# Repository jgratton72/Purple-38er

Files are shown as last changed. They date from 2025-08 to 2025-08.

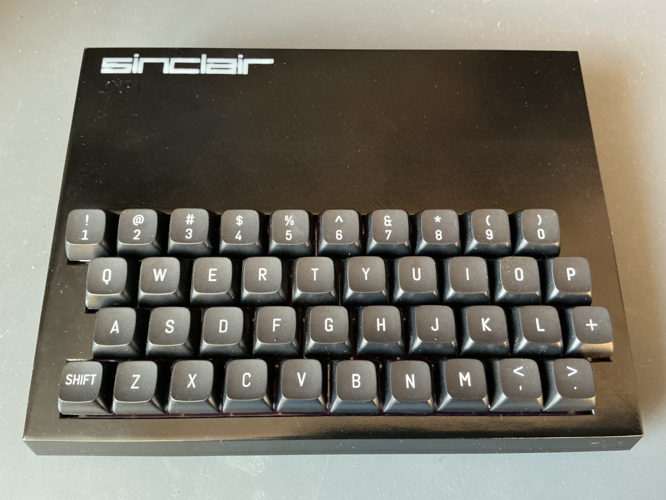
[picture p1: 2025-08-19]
Images/Assembly/IMG_1175.jpeg

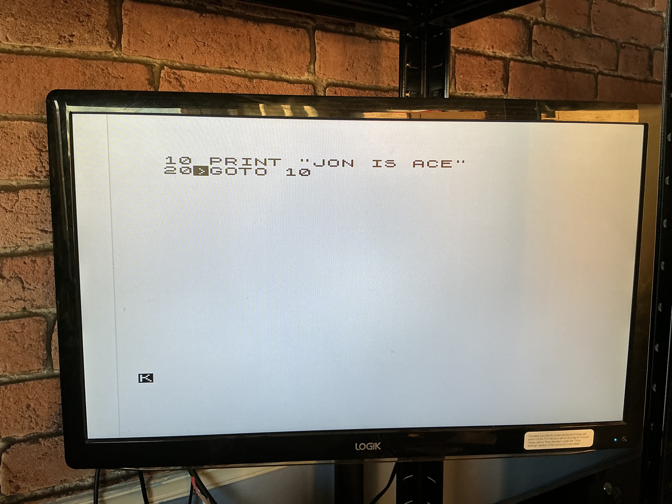
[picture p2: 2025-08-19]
Images/Assembly/IMG_1181.jpeg

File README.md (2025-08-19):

# 🟣 Purple-38er — ZX81+38 Clone (Rev 1.10)

A personal build of the **ZX81+38** clone using purple PCBs and tactile switch keys. This project documents the assembly, troubleshooting, and validation of a modern recreation of the Sinclair ZX81 using standard logic ICs and through-hole components.

---

## 🧰 Project Overview

- **Board Revision**: ZX81+38 Rev 1.10  
- **Design Origin**: Mahjongg’s open-source ZX81+38  
- **Build Variant**: Purple PCB with tactile switch keyboard  
- **Objective**: Achieve reliable boot with “K” prompt, stable composite video, and verified ROM/RAM operation

---

## 🔧 Key Components

| Component | Value / Type | Notes |
|---|---|---|
| Crystal | 13 MHz | Required for correct video timing |
| CPU | Z80A | Clocked at 3.25 MHz (÷4 from crystal)  |
| ROM | 27C256 OTP EPROM | One-time programmable; verified in chip tester |
| RAM | HM62256BLP-7 | Stable operation confirmed |
| RP2 | 22kΩ bussed network | Pull-ups for D0–D7; critical for boot  |
| 74HCU04 | Unbuffered inverter | Required for crystal oscillator |

---

## 🧪 Troubleshooting Log

- **White Screen / No “K” Prompt**:
  - All chips tested in alternate board—confirmed working  
  - RP2 replaced with 22kΩ bussed network—resolved boot issue  
  - Clock verified: 13 MHz at 74HCU04 pin 2, 3.25 MHz at Z80 pin 6

- **ROM Activity**:
  - /CS and /OE toggling observed  
  - Address and data bus activity confirmed

- **Video Output**:
  - Composite waveform present at RCA jack  
  - Sync stable after oscillator validation

---

## 📝 Build Notes

- All decoupling capacitors (100 nF) installed near ICs  
- Socketed chips reseated during debugging  
- Board now boots reliably with “K” prompt and clean composite output

---

## 📷 Visuals

The `images/` folder contains a detailed visual archive of the design and build process:

| Subfolder | Description |
|---|---|
| `Assembly/` | Final integration of keyboard and main PCB into the 3D-printed case |
| `Case 3D/` | 3D design views of the enclosure |
| `Case Printed Raw/`  | Photos of the finished, unassembled printed case |
| `Keyboard 3D/` | 3D renderings of the keyboard layout and switch matrix |
| `Keyboard Build/` | Step-by-step documentation of keyboard assembly |
| `Keycaps/` | Design files and visuals for custom keycaps |
| `PCB 3D/` | 3D views of the main PCB layout and component placement |
| `PCB Build/` | Photo documentation of the main PCB assembly process |

---

## 🛠 Assembly Notes

- **USB Power Connector**:  
   Insulate the top of the USB connector to prevent contact with the underside of the tactile switches.

- **Capacitor C9**:  
  Angle C9 flat 90 degrees away from the main board to avoid shorting against the underside of the tactile switches.
  
  ⚠️ These issues caused keyboard failure when the case was closed.

---

## 📚 References

- [ZX81+38 Original Repository](https://github.com/mahjongg2/ZX81plus38)  
- [RevSpace Project Page](https://revspace.nl/ZX81plus38_simple_to_build_ZX-81_clone)  
- [Forum64 Build Threads](https://www.forum64.de)

---

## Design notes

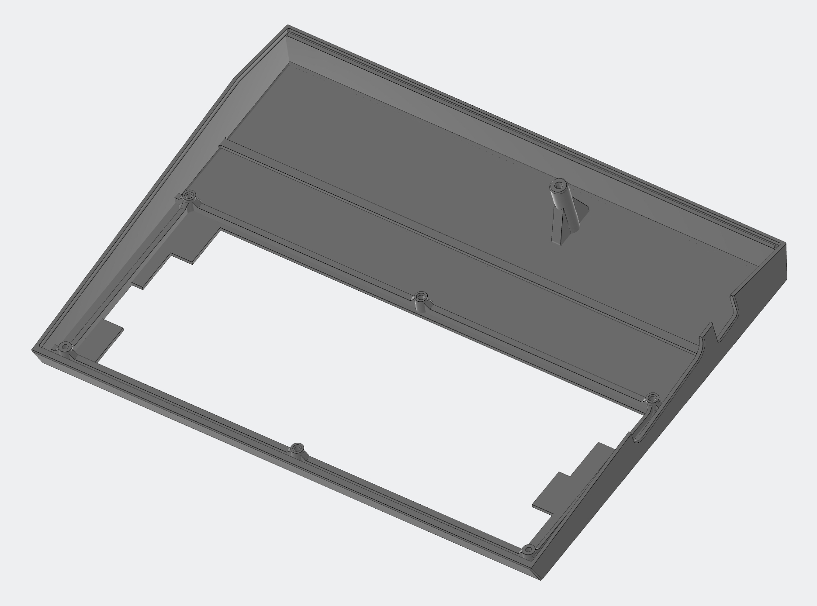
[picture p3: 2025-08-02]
Images/Case 3D/CaseTopInside3D.jpg

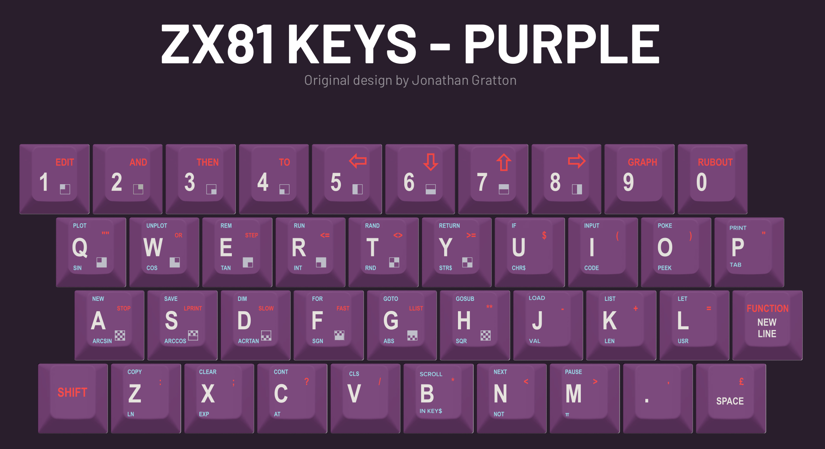
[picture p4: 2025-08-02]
Images/Keycaps/Keycaps.jpg

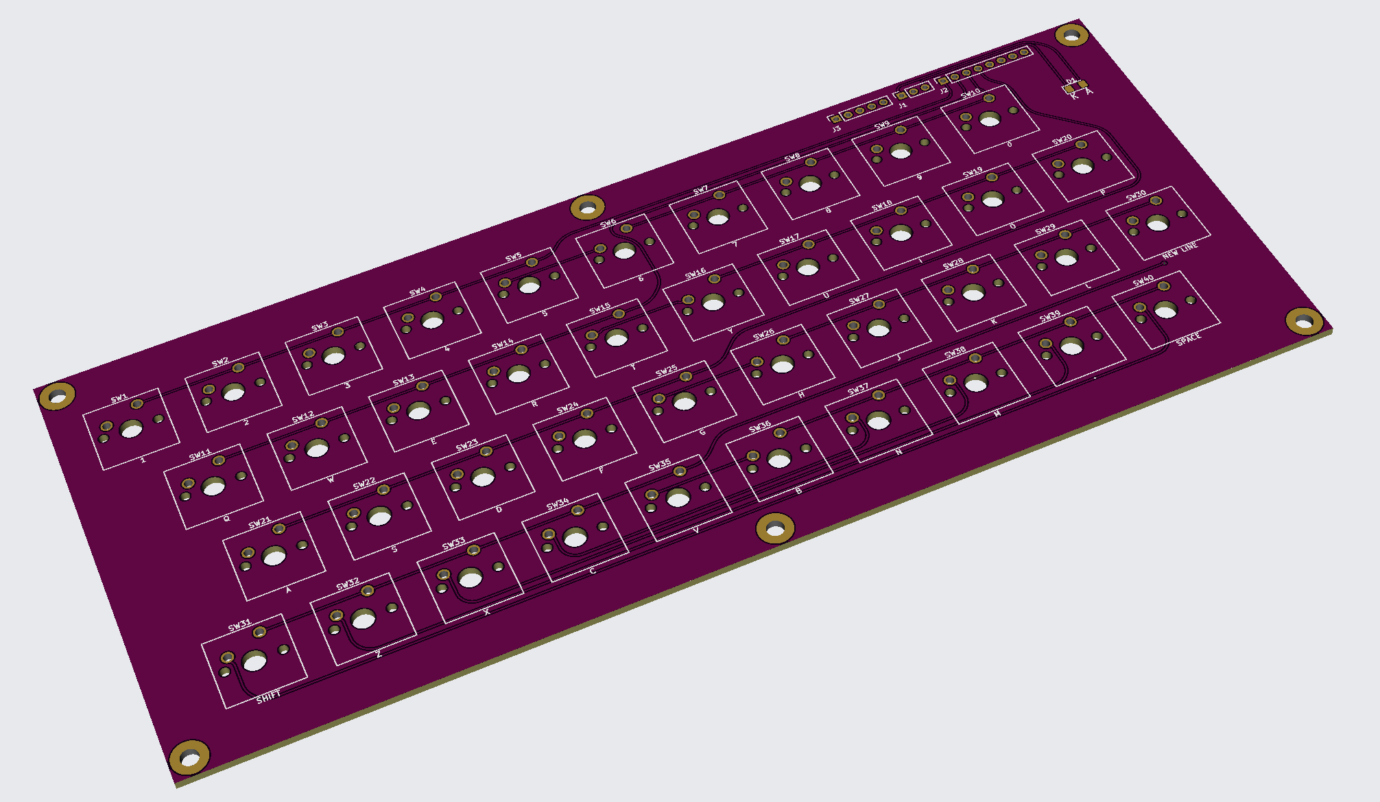
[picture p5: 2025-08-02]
Images/Keyboard 3D/Keyboard3D.jpg

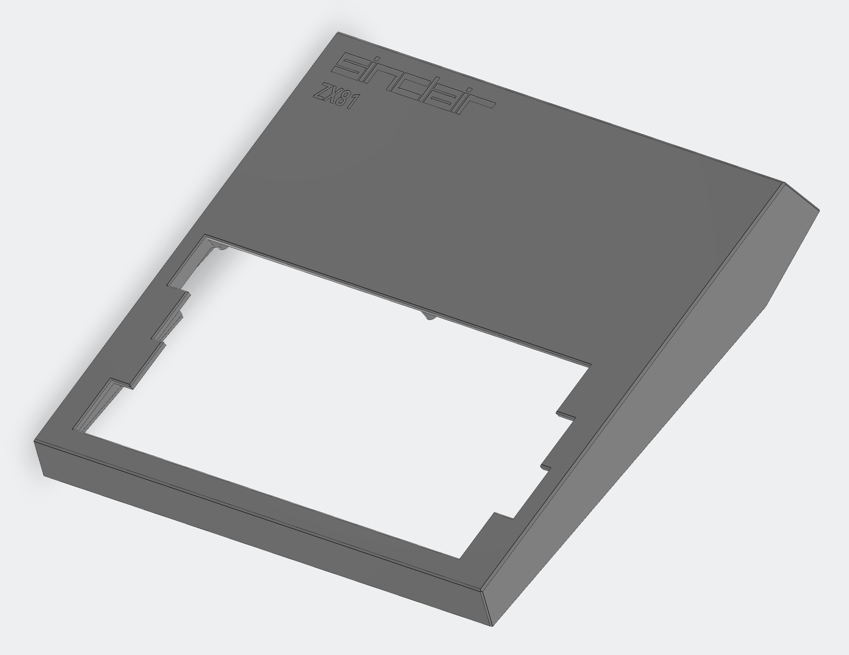
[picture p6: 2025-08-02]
Images/Case 3D/CaseTop3D.jpg

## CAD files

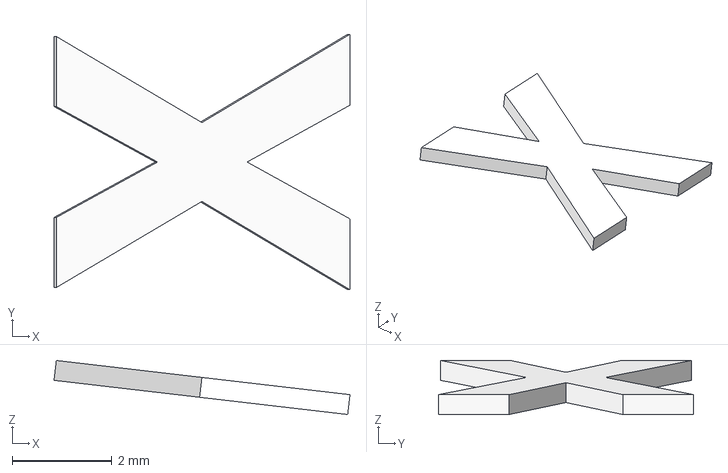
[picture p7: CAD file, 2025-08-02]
Sources/Case/Case STEP/zx81-case-zx81-2.step
5.93 x 5.12 x 1.08 mm

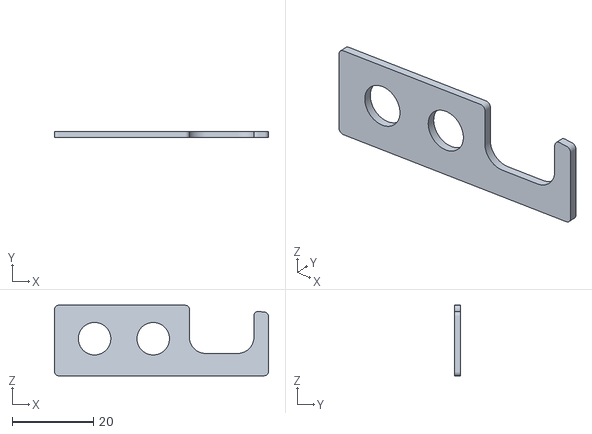
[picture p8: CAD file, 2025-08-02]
Sources/Case/Case STL/zx81-case-port-cover-usb-c.stl
52.8 x 1.60 x 17.4

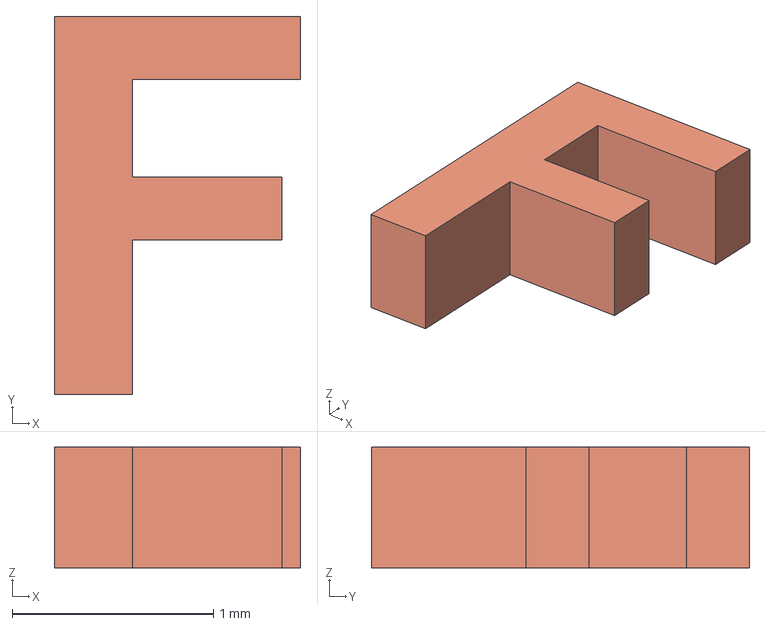
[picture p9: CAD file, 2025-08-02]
Sources/Case/Keycap STEP/zx81-keycaps-text-b-76.step
1.22 x 1.88 x 0.6 mm

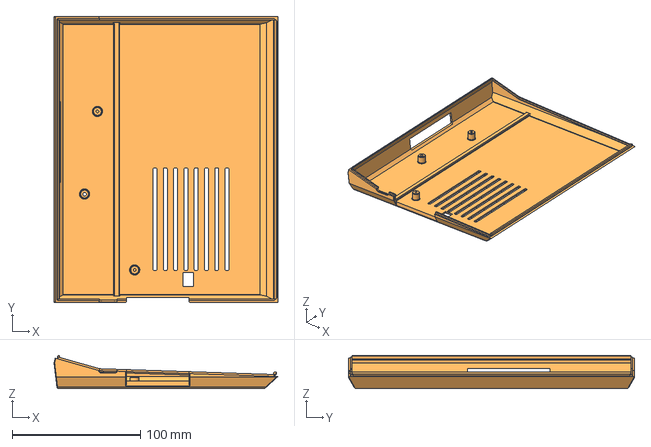
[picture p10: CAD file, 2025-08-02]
Sources/Case/Case STEP/zx81-case-bottom-zx81.step
174.4 x 223.0 x 25.7 mm

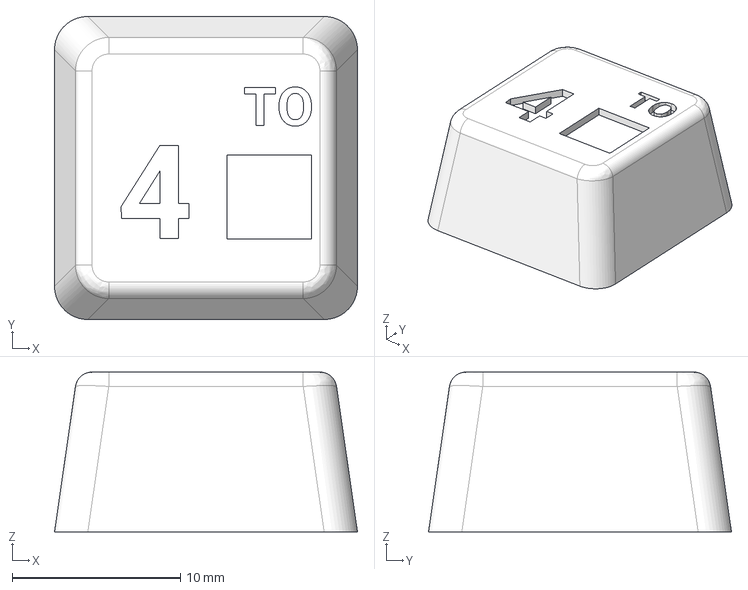
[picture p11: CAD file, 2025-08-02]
Sources/Case/Keycap STEP/zx81-keycaps-4.step
18.0 x 18.0 x 9.50 mm

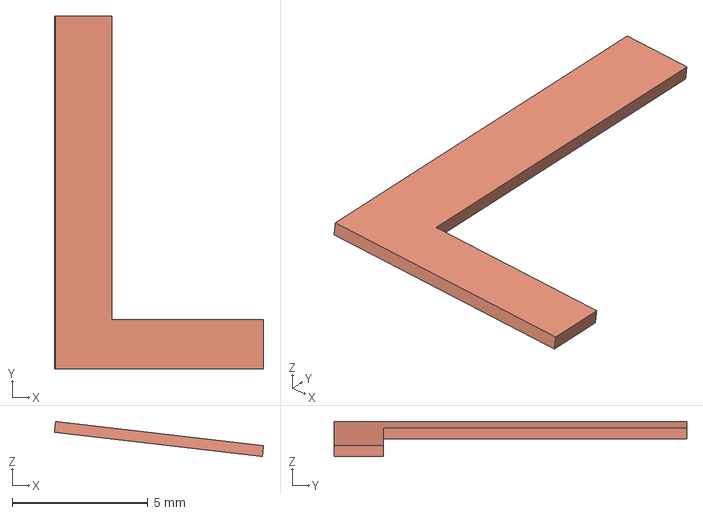
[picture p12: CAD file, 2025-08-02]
Sources/Case/Case STEP/zx81-case-sinclair.step
7.71 x 13.0 x 1.29 mm

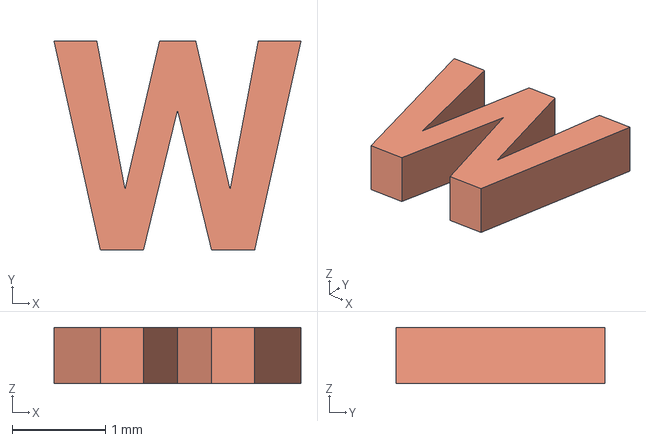
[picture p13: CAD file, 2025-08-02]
Sources/Case/Keycap STEP/zx81-keycaps-text-b-25.step
2.65 x 2.23 x 0.6 mm

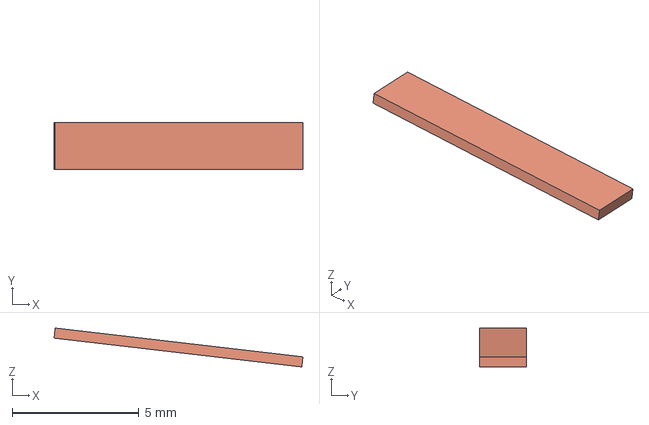
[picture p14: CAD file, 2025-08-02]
Sources/Case/Case STEP/zx81-case-sinclair-7.step
9.81 x 1.86 x 1.53 mm

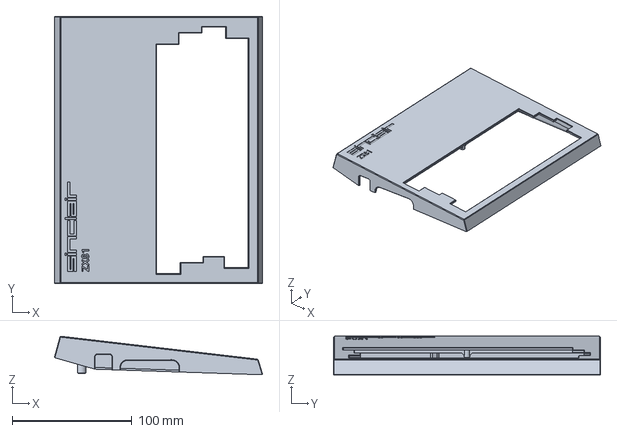
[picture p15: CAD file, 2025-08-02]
Sources/Case/Case STEP/zx81-case-top-zx81.step
174.0 x 223.0 x 32.2 mm

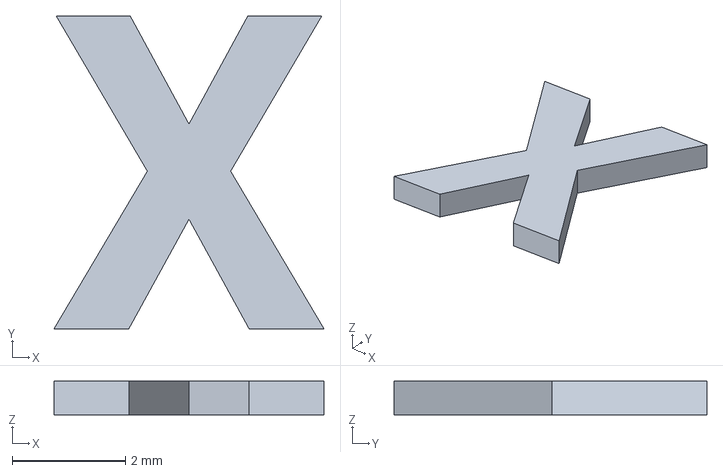
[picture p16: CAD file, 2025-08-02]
Sources/Case/Keycap STEP/zx81-keycaps-text-a-24.step
4.78 x 5.53 x 0.6 mm

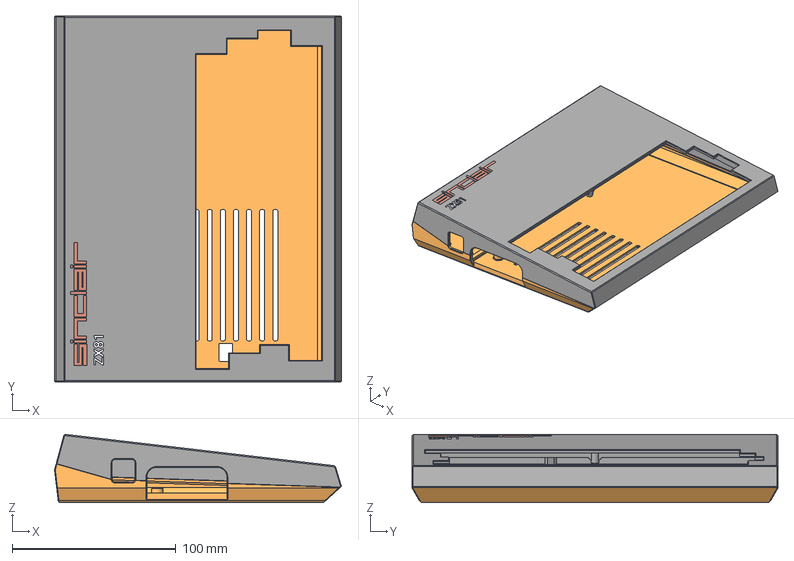
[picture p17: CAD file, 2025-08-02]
Sources/Case/Case STEP/combined-zx81-case-zx81.step
175.0 x 223.0 x 41.7 mm

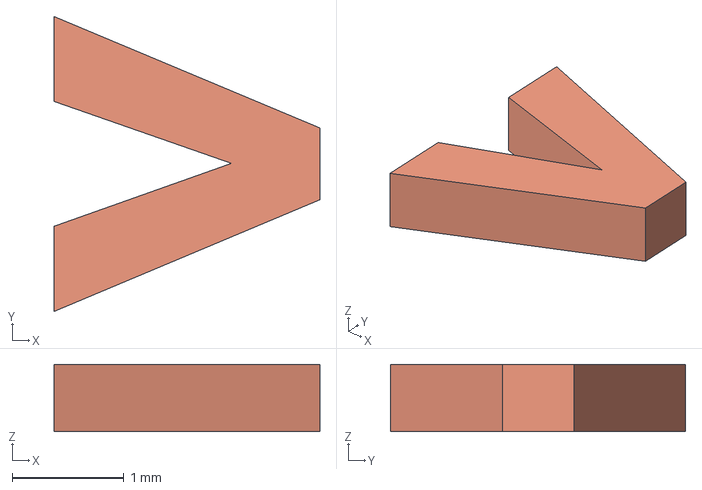
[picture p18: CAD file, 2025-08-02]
Sources/Case/Keycap STEP/zx81-keycaps-text-b-19.step
2.38 x 2.64 x 0.6 mm

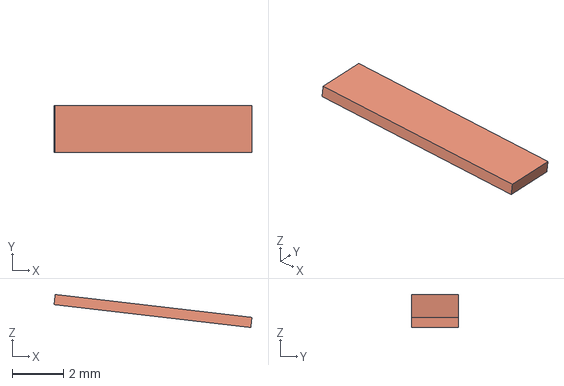
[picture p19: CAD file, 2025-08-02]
Sources/Case/Case STEP/zx81-case-sinclair-2.step
7.73 x 1.85 x 1.29 mm

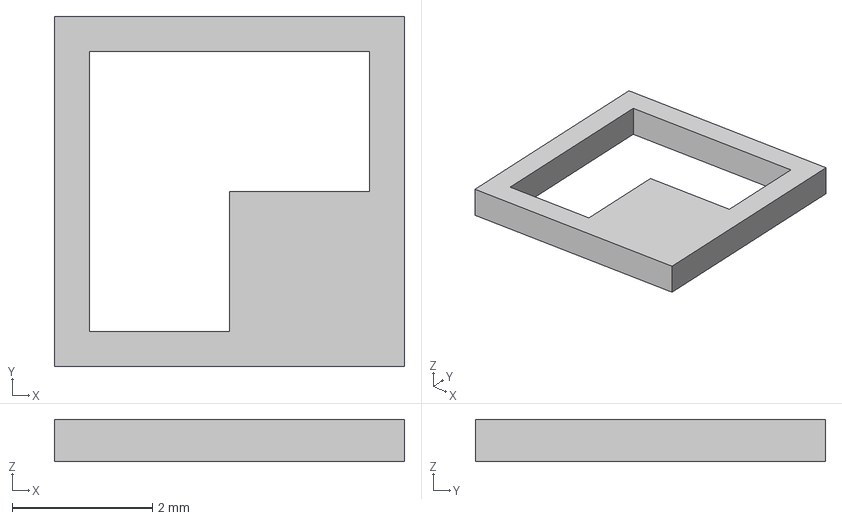
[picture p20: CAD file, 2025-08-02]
Sources/Case/Keycap STEP/zx81-keycaps-dark-19.step
5.00 x 5.00 x 0.6 mm

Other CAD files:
Sources/Case/Keycap STEP/zx81-keycaps-n.step
Sources/Case/Case STEP/zx81-case-sinclair-5.step
Sources/Case/Keycap STEP/zx81-keycaps-text-a-30.step
Sources/Case/Case STEP/zx81-case-top-timex.step
Sources/Case/Case STEP/combined-zx81-case-timex.step
Sources/Case/Case STEP/zx81-case-bottom-timex.step
Sources/Case/Case STEP/zx81-case-port-cover.step
Sources/Case/Case STEP/zx81-case-sinclair-1.step
Sources/Case/Case STEP/zx81-case-sinclair-3.step
Sources/Case/Case STEP/zx81-case-sinclair-4.step
Sources/Case/Case STEP/zx81-case-sinclair-6.step
Sources/Case/Case STEP/zx81-case-sinclair-8.step
Sources/Case/Case STEP/zx81-case-sinclair-9.step
Sources/Case/Case STEP/zx81-case-usb-mount.step
Sources/Case/Case STEP/zx81-case-zx81-1.step
Sources/Case/Case STEP/zx81-case-zx81-3.step
Sources/Case/Case STEP/zx81-case-zx81.step
Sources/Case/Case STL/zx81-case-bottom-timex.stl
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

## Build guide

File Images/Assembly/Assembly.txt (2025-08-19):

Notes.
Had to lay C9 flat and put some insulation on top of the USB power to keep them from shorting the keyboard.
before i did that the keyboard would not work when I clipped the case shut.

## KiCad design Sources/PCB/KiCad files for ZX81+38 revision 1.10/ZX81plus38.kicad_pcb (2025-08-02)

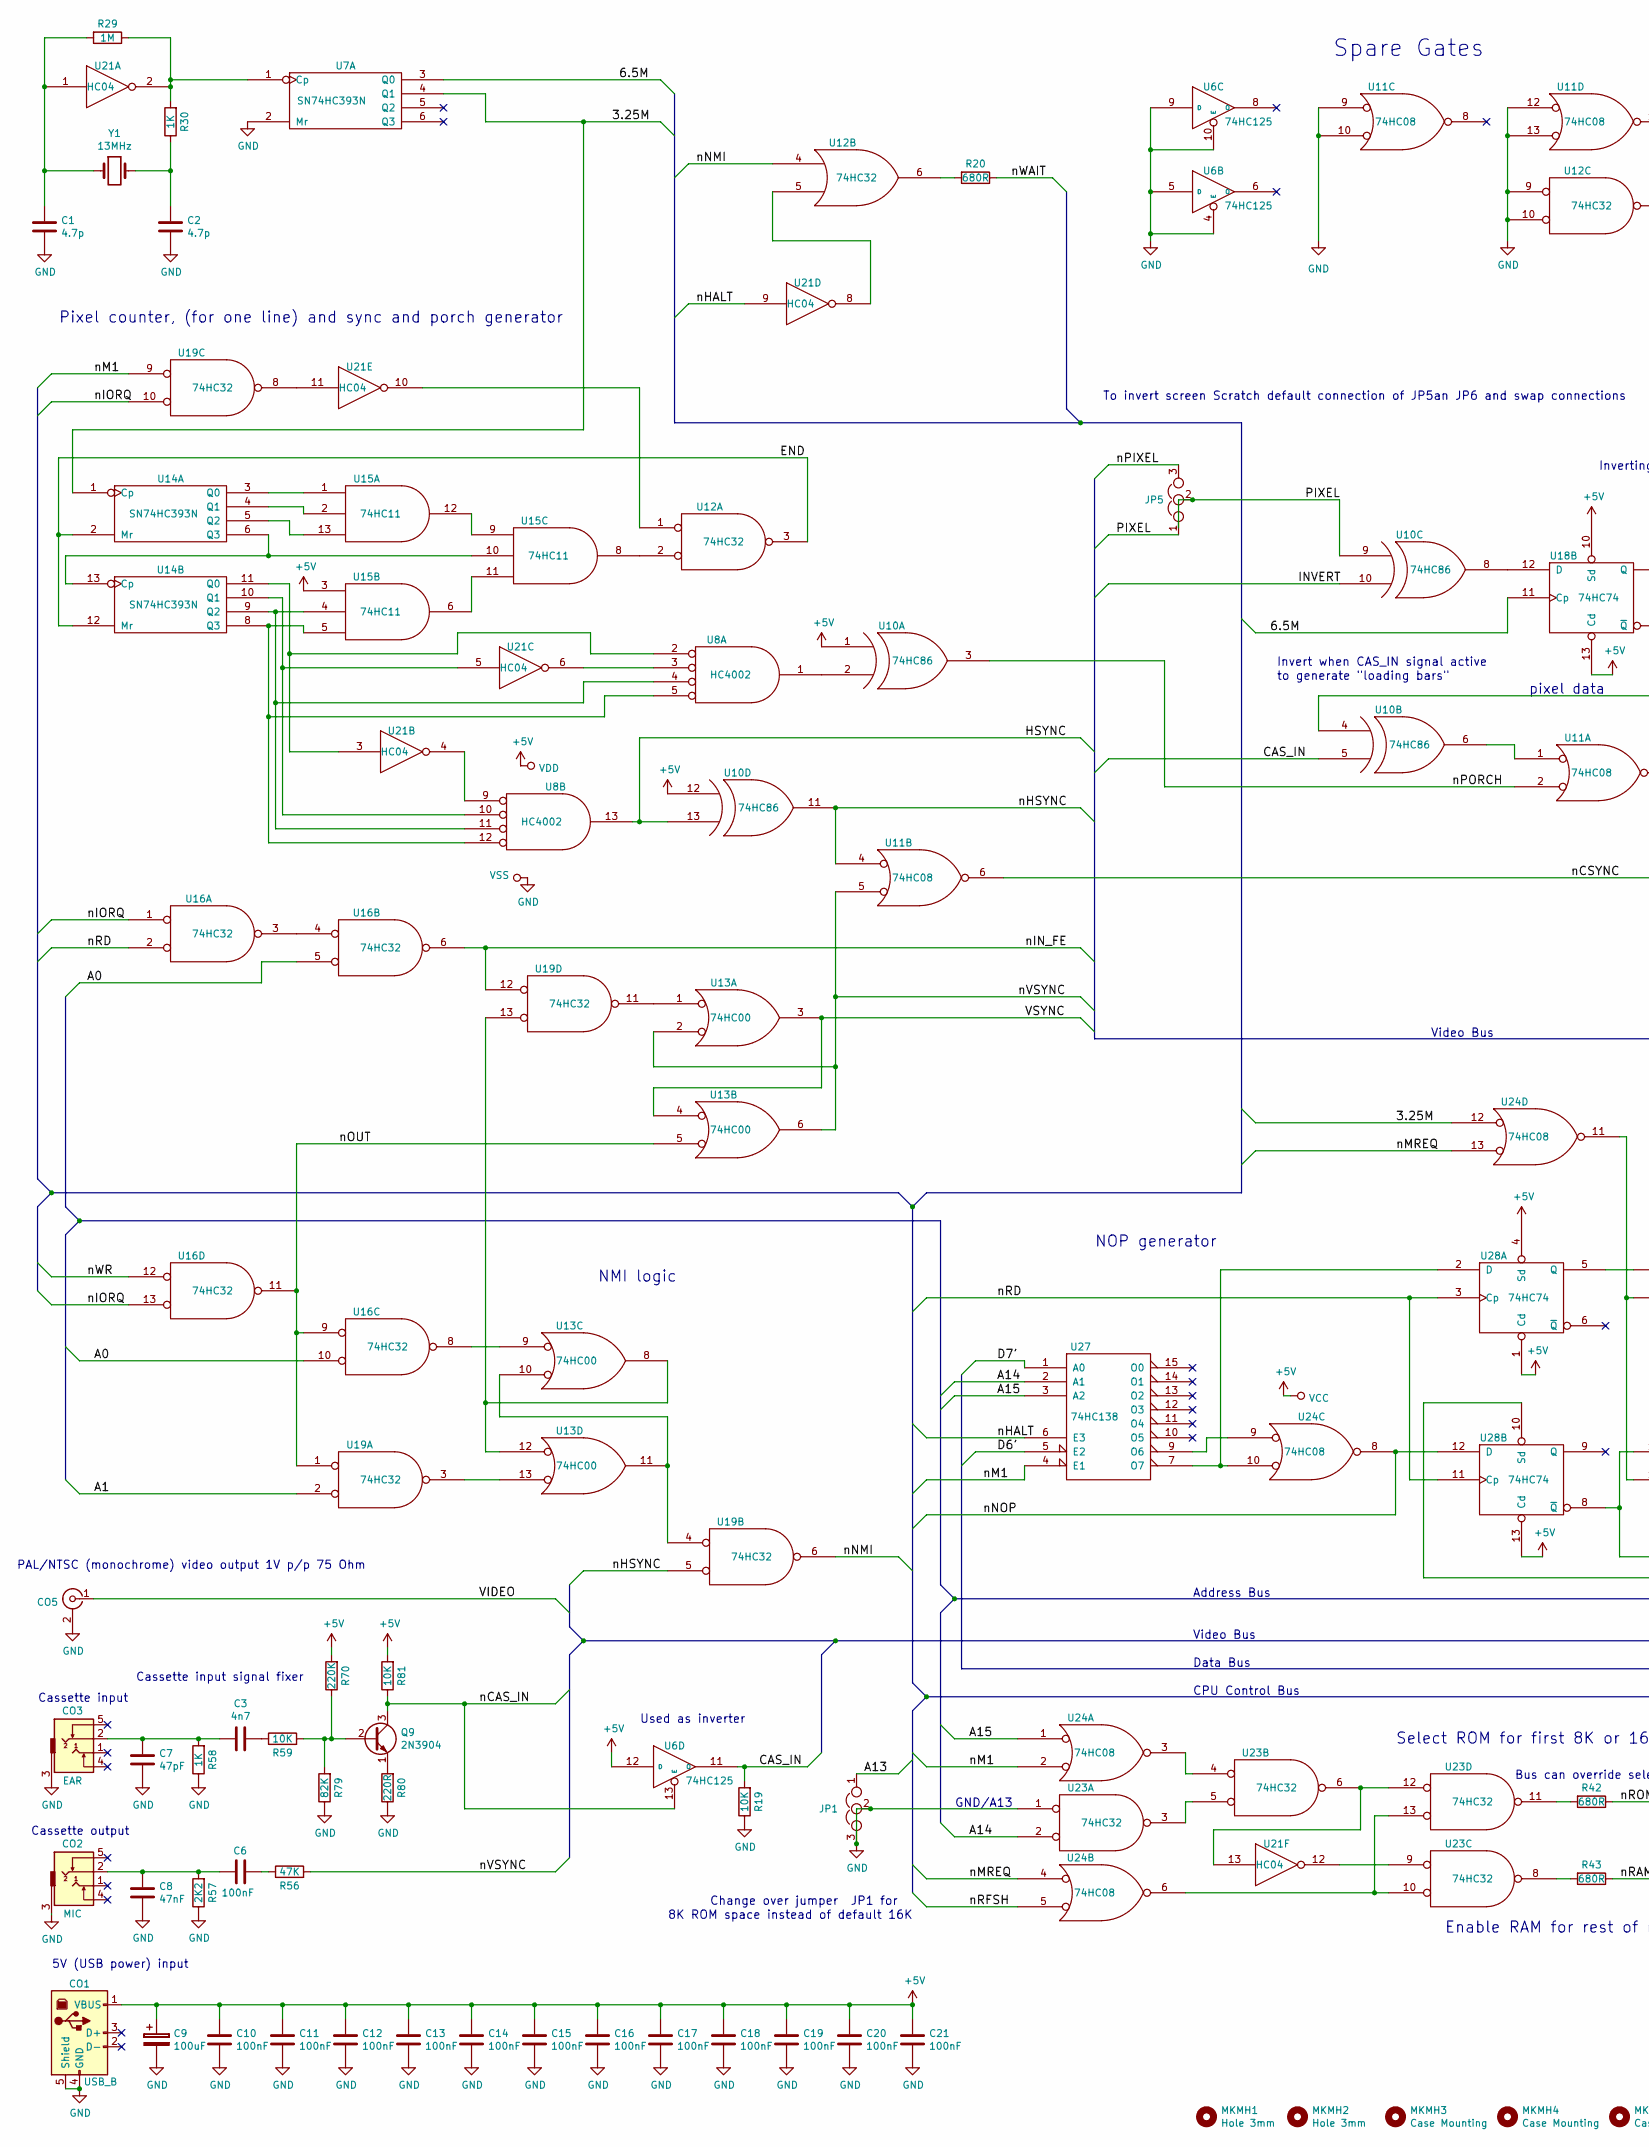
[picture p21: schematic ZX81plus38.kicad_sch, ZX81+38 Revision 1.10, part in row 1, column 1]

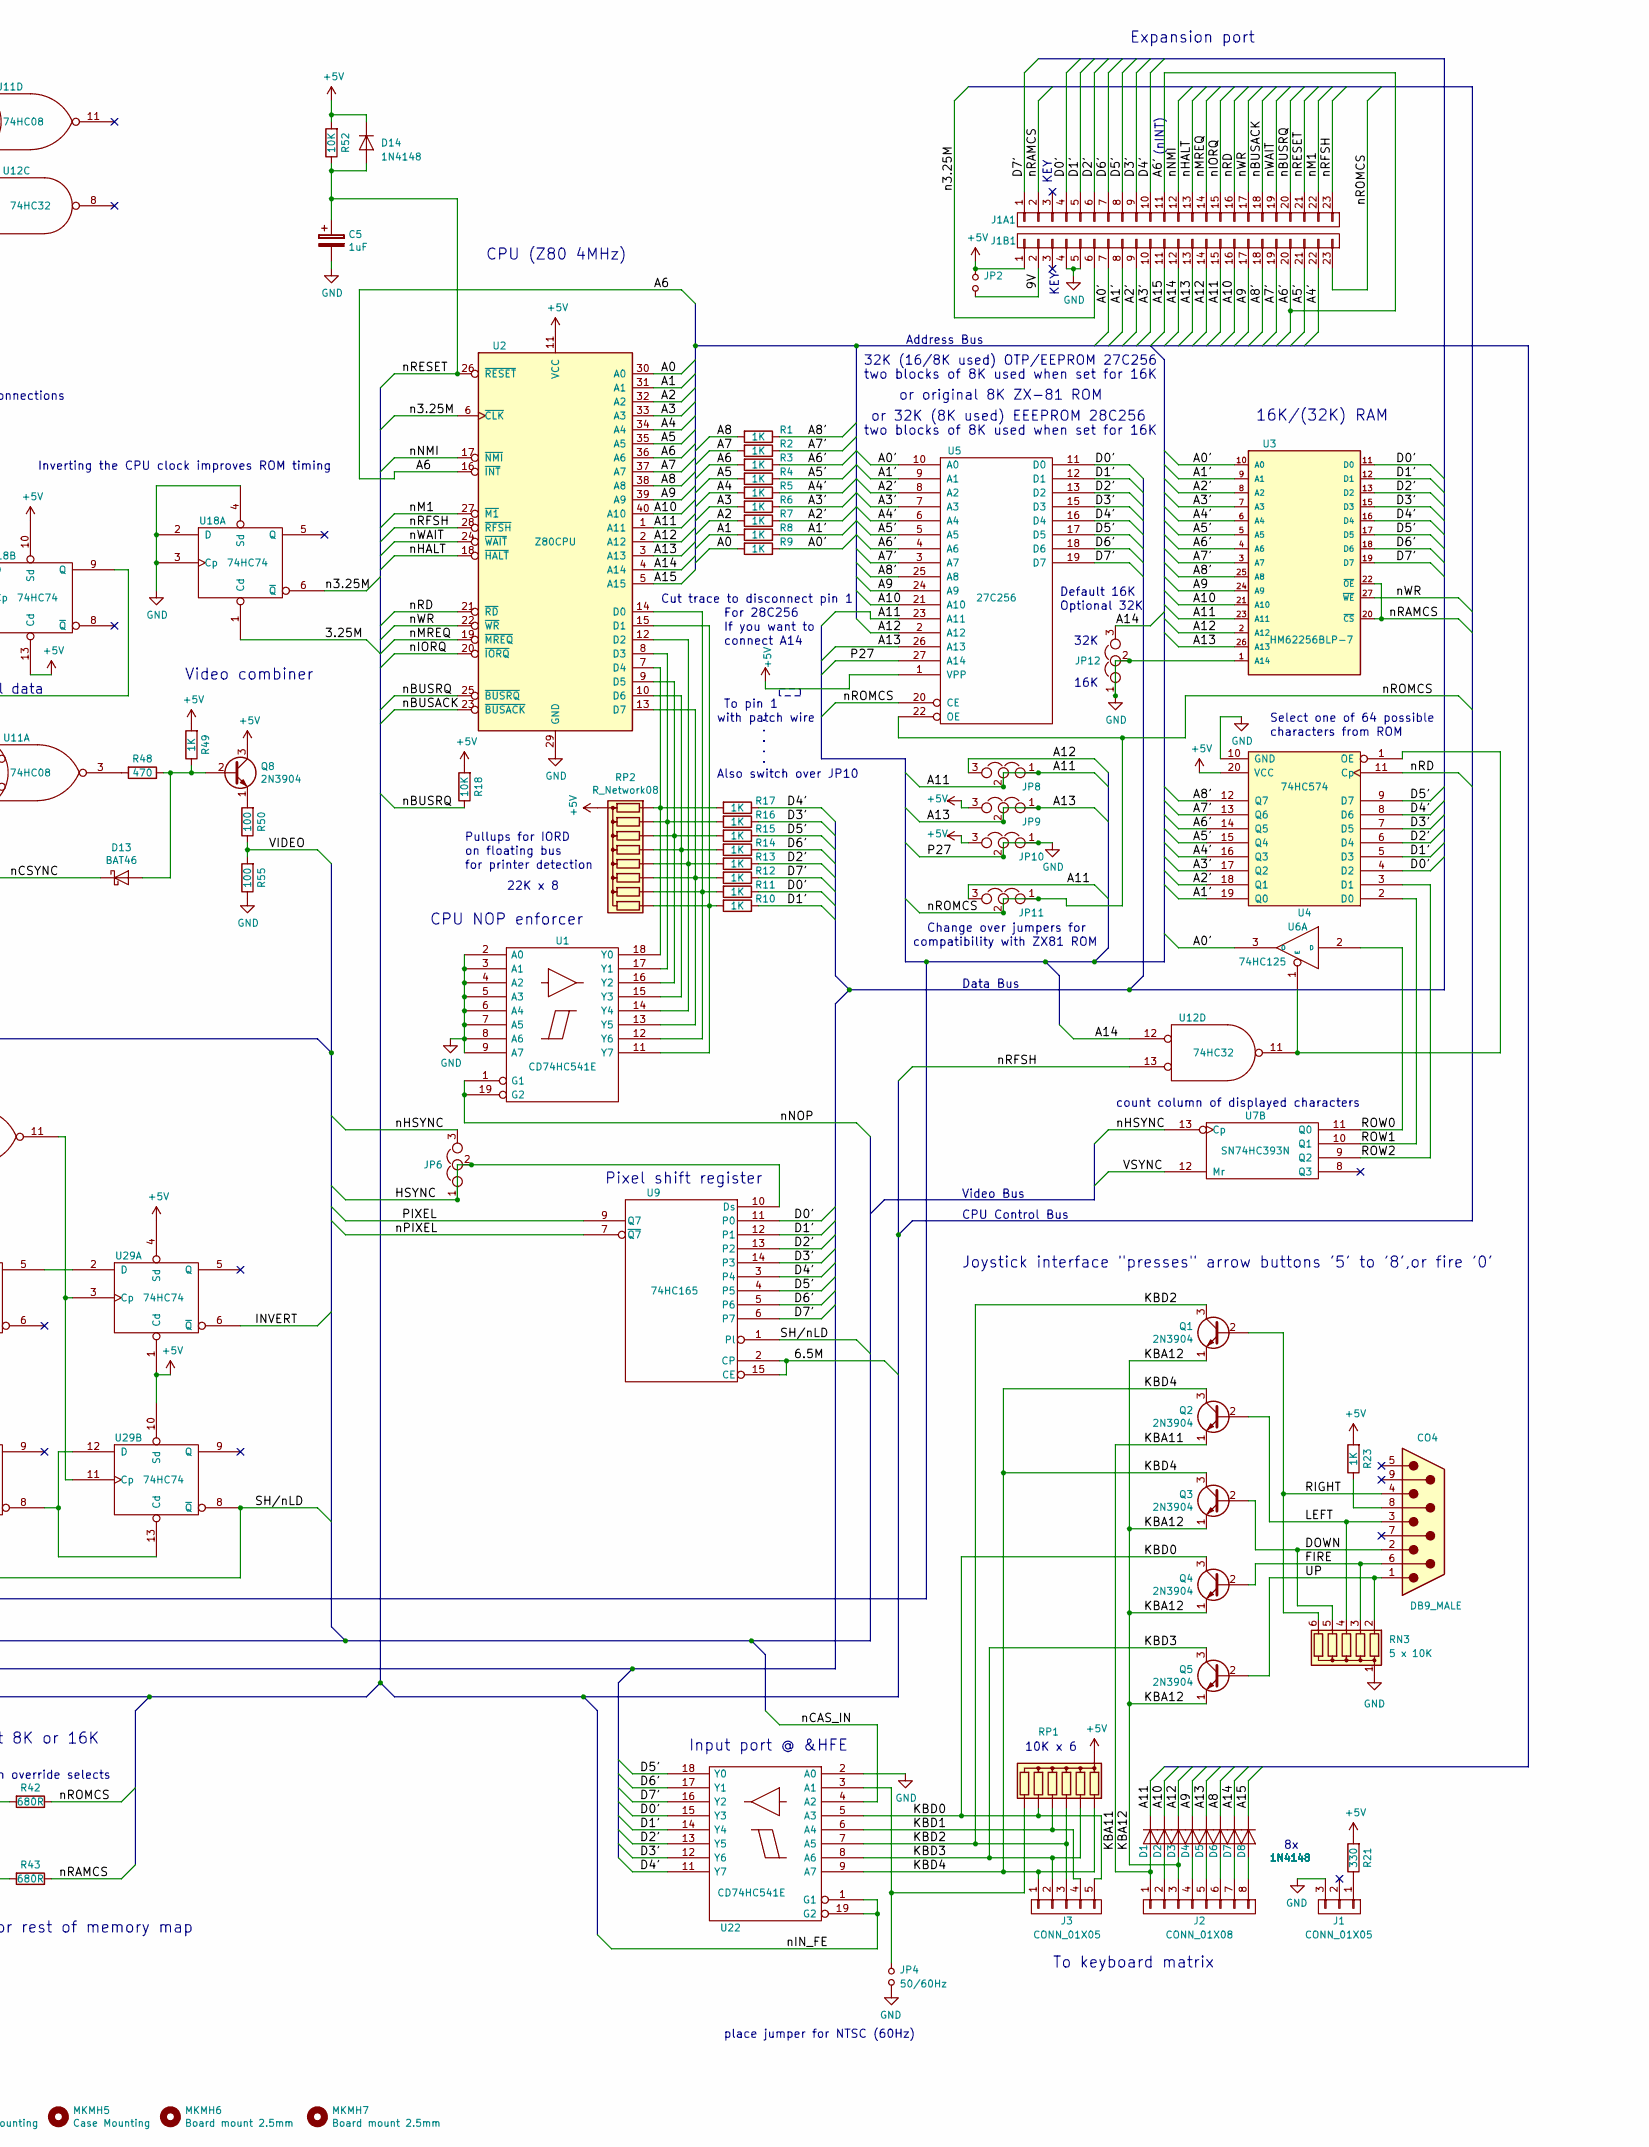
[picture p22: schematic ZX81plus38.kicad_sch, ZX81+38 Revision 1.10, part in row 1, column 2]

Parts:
C1, C2: 4.7p; C_Disc_D3.0mm_W2.0mm_P2.50mm
C3: 4n7; C_Disc_D4.7mm_W2.5mm_P5.00mm
C5: 1uF; CP_Radial_Tantal_D6.0mm_P2.50mm
C6, C10, C11, C12, C13, C14, C15, C16, C17, C18, C19, C20, C21: 100nF; C_Disc_D4.7mm_W2.5mm_P5.00mm
C7: 47pF; C_Disc_D4.7mm_W2.5mm_P5.00mm
C8: 47nF; C_Disc_D4.7mm_W2.5mm_P5.00mm
C9: 100uF; CP_Radial_Tantal_D6.0mm_P2.50mm
CO1: USB_B
CO2: MIC; SPC21348
CO3: EAR; SPC21348
CO4: DB9_MALE; dB09-MALE
CO5: CONN_COAXIAL; RCA_CONNECTOR
D1, D2, D3, D4, D5, D6, D7, D8, D14: 1N4148; D_DO-35_SOD27_P7.62mm_Horizontal
D13: BAT46; D_DO-35_SOD27_P7.62mm_Horizontal
J1: CONN_01X05; Pin_Header_Straight_1x03_Pitch2.54mm
J1A1, J1B1: CONN_01X23; Pin_Header_Straight_1x23_Pitch2.54mm
J2: CONN_01X08; Pin_Header_Straight_1x08_Pitch2.54mm
J3: CONN_01X05; Pin_Header_Straight_1x05_Pitch2.54mm
JP1, JP5, JP6, JP8, JP9, JP10, JP11, JP12: Jumper_NC_Dual; Pin_Header_Straight_1x03_Pitch2.54mm
JP2: .; Pin_Header_Straight_1x02_Pitch2.54mm
JP4: 50/60Hz; Pin_Header_Straight_1x02_Pitch2.54mm
MKMH1, MKMH2: Hole 3mm; MountingHole_3.2mm_M3
MKMH3, MKMH4, MKMH5: Case Mounting; MountingHole_3.2mm_M3
MKMH6, MKMH7: Board mount 2.5mm; MountingHole_2.5mm
Q1, Q2, Q3, Q4, Q5, Q8, Q9: 2N3904; TO-92_Molded_Narrow
R1, R2, R3, R4, R5, R6, R7, R8, R9, R10, R11, R12, R13, R14, R15, R16, R17, R23, R58: 1K; R_Axial_DIN0204_L3.6mm_D1.6mm_P2.54mm_Vertical
R18, R19, R52, R59, R81: 10K; R_Axial_DIN0204_L3.6mm_D1.6mm_P2.54mm_Vertical
R20, R42, R43: 680R; R_Axial_DIN0204_L3.6mm_D1.6mm_P2.54mm_Vertical
R21: 330; R_Axial_DIN0207_L6.3mm_D2.5mm_P7.62mm_Horizontal
R29: 1M; R_Axial_DIN0207_L6.3mm_D2.5mm_P7.62mm_Horizontal
R30, R49: 1K; R_Axial_DIN0207_L6.3mm_D2.5mm_P7.62mm_Horizontal
R48: 470; R_Axial_DIN0207_L6.3mm_D2.5mm_P7.62mm_Horizontal
R50, R55: 100; R_Axial_DIN0207_L6.3mm_D2.5mm_P7.62mm_Horizontal
R56: 47K; R_Axial_DIN0204_L3.6mm_D1.6mm_P2.54mm_Vertical
R57: 2K2; R_Axial_DIN0204_L3.6mm_D1.6mm_P2.54mm_Vertical
R70: 220K; R_Axial_DIN0204_L3.6mm_D1.6mm_P2.54mm_Vertical
R79: 82K; R_Axial_DIN0204_L3.6mm_D1.6mm_P2.54mm_Vertical
R80: 220R; R_Axial_DIN0204_L3.6mm_D1.6mm_P2.54mm_Vertical
RN3: 5 x 10K; R_Array_SIP6
RP1: R_Network06; R_Array_SIP7
RP2: R_Network08; R_Array_SIP9
U1, U22: CD74HC541E; DIP-20_Ideal
U2: Z80CPU; DIP-40_ideal
U3: HM62256BLP-7; DIP-28_Ideal
U4: 74HC574; DIP-20_Ideal
U5: 27C256; DIP-28_Ideal
U6: 74HC125; DIP-14_Socket_Ideal
U7, U14: SN74HC393N; DIP-14_Socket_Ideal
U8: HC4002; DIP-14_Socket_Ideal
U9: 74HC165; DIP-16_Ideal
U10: 74HC86; DIP-14_Socket_Ideal
U11, U24: 74HC08; DIP-14_Socket_Ideal
U12, U16, U19, U23: 74HC32; DIP-14_Socket_Ideal
U13: 74HC00; DIP-14_Socket_Ideal
U15: 74HC11; DIP-14_Socket_Ideal
U18, U28, U29: 74HC74; DIP-14_Socket_Ideal
U21: HC04; DIP-14_Socket_Ideal
U27: 74HC138; DIP-16_Ideal
Y1: 13MHz; Crystal_SMD_HC49-SD

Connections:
+5V: C9.1, C10.2, C11.2, C12.2, C13.2, C14.2, C15.2, C16.2, C17.2, C18.2, C19.2, C20.2, C21.2, CO1.1 (VBUS), D14.1 (K), J1B1.1, JP2.1, JP9.3, JP10.3, Q8.3 (C), R18.2, R21.2, R23.2, R49.2, R52.2, R70.2, R81.2, RP1.1 (common), RP2.1 (common), U1.20 (VCC), U2.11 (VCC), U3.28 (VCC), U4.20 (VCC), U5.1 (VPP), U5.28 (VCC), U6.12 (D), U6.14 (VCC), U7.14 (VCC), U8.14 (VDD), U9.16 (VCC), U10.1 (IN1), U10.12 (IN1), U10.14 (VCC), U11.14 (VCC), U12.14 (VCC), U13.14 (VCC), U14.14 (VCC), U15.3, U15.14 (VCC), U16.14 (VCC), U18.10 (Sd), U18.13 (Cd), U18.14 (VCC), U19.14 (VCC), U21.14 (VCC), U22.20 (VCC), U23.14 (VCC), U24.14 (VCC), U27.16 (VCC), U28.1 (Cd), U28.4 (Sd), U28.13 (Cd), U28.14 (VCC), U29.1 (Cd), U29.4 (Sd), U29.10 (Sd), U29.14 (VCC)
/3.25M: U7.4 (Q1), U14.1 (Cp), U18.1 (Cd), U24.12
/6.5M: U7.3 (Q0), U9.2 (CP), U9.15 (CE), U18.11 (Cp)
/9V: J1B1.2, JP2.2
/A0: R9.2, U2.30 (A0), U16.5, U16.10
/A0': J1B1.7, R9.1, U3.10 (A0), U5.10 (A0), U6.3 (O)
/A1: R8.2, U2.31 (A1), U19.2
/A1': J1B1.8, R8.1, U3.9 (A1), U4.19 (Q0), U5.9 (A1)
/A2: R7.2, U2.32 (A2)
/A2': J1B1.9, R7.1, U3.8 (A2), U4.18 (Q1), U5.8 (A2)
/A3: R6.2, U2.33 (A3)
/A3': J1B1.10, R6.1, U3.7 (A3), U4.17 (Q2), U5.7 (A3)
/A4: R5.2, U2.34 (A4)
/A4': J1B1.22, R5.1, U3.6 (A4), U4.16 (Q3), U5.6 (A4)
/A5: R4.2, U2.35 (A5)
/A5': J1B1.21, R4.1, U3.5 (A5), U4.15 (Q4), U5.5 (A5)
/A6: R3.2, U2.16 (~INT), U2.36 (A6)
/A6': J1A1.11, J1B1.20, R3.1, U3.4 (A6), U4.14 (Q5), U5.4 (A6)
/A7: R2.2, U2.37 (A7)
/A7': J1B1.19, R2.1, U3.3 (A7), U4.13 (Q6), U5.3 (A7)
/A8: D6.1 (K), R1.2, U2.38 (A8)
/A8': J1B1.18, R1.1, U3.25 (A8), U4.12 (Q7), U5.25 (A8)
/A9: D4.1 (K), J1B1.17, U2.39 (A9), U3.24 (A9), U5.24 (A9)
/A10: D2.1 (K), J1B1.16, U2.40 (A10), U3.21 (A10), U5.21 (A10)
/A11: D1.1 (K), J1B1.15, JP8.1, JP8.2, JP11.3, U2.1 (A11), U3.23 (A11), U5.23 (A11)
/A12: D3.1 (K), J1B1.14, JP8.3, U2.2 (A12), U3.2 (A12), U5.2 (A12)
/A13: D5.1 (K), J1B1.13, JP1.1, JP9.1, JP9.2, U2.3 (A13), U3.26 (A13), U5.26 (A13)
/A14: D7.1 (K), J1B1.12, JP12.3, U2.4 (A14), U12.12, U23.2, U27.2 (A1)
/A15: D8.1 (K), J1B1.11, U2.5 (A15), U24.1, U27.3 (A2)
/CAS_IN: R19.2, U6.11 (O), U10.5 (IN2)
/D0': J1A1.4, R11.1, U3.11 (D0), U4.4 (D2), U5.11 (D0), U9.11 (P0), U22.15 (Y3)
/D1': J1A1.5, R10.1, U3.12 (D1), U4.5 (D3), U5.12 (D1), U9.12 (P1), U22.14 (Y4)
/D2': J1A1.6, R13.1, U3.13 (D2), U4.6 (D4), U5.13 (D2), U9.13 (P2), U22.13 (Y5)
/D3': J1A1.9, R16.1, U3.15 (D3), U4.7 (D5), U5.15 (D3), U9.14 (P3), U22.12 (Y6)
/D4': J1A1.10, R17.1, U3.16 (D4), U4.8 (D6), U5.16 (D4), U9.3 (P4), U22.11 (Y7)
/D5': J1A1.8, R15.1, U3.17 (D5), U4.9 (D7), U5.17 (D5), U9.4 (P5), U22.18 (Y0)
/D6': J1A1.7, R14.1, U3.18 (D6), U5.18 (D6), U9.5 (P6), U22.17 (Y1), U27.5 (E2)
/D7': J1A1.1, R12.1, U3.19 (D7), U5.19 (D7), U9.6 (P7), U22.16 (Y2), U27.1 (A0)
/DOWN: CO4.2, Q3.2 (B), RN3.5 (R4)
/END: U12.3, U14.2 (Mr), U14.12 (Mr)
/FIRE: CO4.6, Q4.2 (B), RN3.3 (R2)
/HSYNC: JP6.1, JP6.2, U8.13, U9.10 (Ds), U10.13 (IN2)
/INVERT: U10.10 (IN2), U29.6 (~Q)
/KBA11: D1.2 (A), J2.1, Q2.1 (E)
/KBA12: D3.2 (A), J2.3, Q1.1 (E), Q3.1 (E), Q4.1 (E), Q5.1 (E)
/KBD0: J3.5, Q4.3 (C), RP1.6 (R5), U22.5 (A3)
/KBD1: J3.4, RP1.5 (R4), U22.6 (A4)
/KBD2: J3.3, Q1.3 (C), RP1.4 (R3), U22.7 (A5)
/KBD3: J3.2, Q5.3 (C), RP1.3 (R2), U22.8 (A6)
/KBD4: J3.1, Q2.3 (C), Q3.3 (C), RP1.2 (R1), U22.9 (A7)
/LEFT: CO4.3, Q2.2 (B), RN3.4 (R3)
/PIXEL: JP5.1, JP5.2, U9.9 (Q7), U10.9 (IN1)
/RIGHT: CO4.4, Q1.2 (B), RN3.6 (R5)
/ROW0: U6.2 (D), U7.11 (Q0)
/ROW1: U4.2 (D0), U7.10 (Q1)
/ROW2: U4.3 (D1), U7.9 (Q2)
/SH/nLD: U9.1 (Pl), U28.10 (Sd), U29.8 (~Q)
/UP: CO4.1, Q5.2 (B), RN3.2 (R1)
/VIDEO: CO5.1 (In), R50.1, R55.2
/VSYNC: U7.12 (Mr), U13.3, U13.4
/n3.25M: J1B1.6, U2.6 (~CLK), U18.6 (~Q)
/nBUSACK: J1A1.18, U2.23 (~BUSACK)
/nBUSRQ: J1A1.20, R18.1, U2.25 (~BUSRQ)
/nCAS_IN: Q9.3 (C), R81.1, U6.13 (E), U22.4 (A2)
/nCSYNC: D13.1 (K), U11.6
/nHALT: J1A1.13, U2.18 (~HALT), U21.9, U27.6 (E3)
/nHSYNC: JP6.3, U7.13 (Cp), U10.11 (OUT), U11.4, U19.5
/nIN_FE: U16.6, U19.12, U22.1 (G1), U22.19 (G2)
/nIORQ: J1A1.15, U2.20 (~IORQ), U16.1, U16.13, U19.10
/nM1: J1A1.22, U2.27 (~M1), U19.9, U24.2, U27.4 (E1)
/nMREQ: J1A1.14, U2.19 (~MREQ), U24.4, U24.13
/nNMI: J1A1.12, U2.17 (~NMI), U12.4, U19.6
/nNOP: U1.1 (G1), U1.19 (G2), U24.8, U28.12 (D)
/nOUT: U13.5, U16.9, U16.11, U19.1
/nPIXEL: JP5.3, U9.7 (~Q7)
/nPORCH: U10.3 (OUT), U11.2
/nRAMCS: J1A1.2, R43.1, U3.20 (~CS), U3.22 (~OE)
/nRD: J1A1.16, U2.21 (~RD), U4.11 (Cp), U16.2, U28.3 (Cp), U28.11 (Cp)
/nRESET: C5.1, D14.2 (A), J1A1.21, R52.1, U2.26 (~RESET)
/nRFSH: J1A1.23, U2.28 (~RFSH), U12.13, U24.5
/nROMCS: J1B1.23, JP11.1, JP11.2, R42.1, U5.20 (CE), U5.22 (OE)
/nVSYNC: R56.2, U11.5, U13.2, U13.6
/nWAIT: J1A1.19, R20.1, U2.24 (~WAIT)
/nWR: J1A1.17, U2.22 (~WR), U3.27 (~WE), U16.12
GND: C1.2, C2.2, C5.2, C7.2, C8.2, C9.2, C10.1, C11.1, C12.1, C13.1, C14.1, C15.1, C16.1, C17.1, C18.1, C19.1, C20.1, C21.1, CO1.4 (GND), CO1.5 (Shield), CO2.3, CO3.3, CO5.2 (Ext), J1.3, J1B1.4, J1B1.5, JP1.2, JP1.3, JP4.2, JP10.1, JP10.2, JP12.1, JP12.2, R19.1, R55.1, R57.1, R58.1, R79.1, R80.1, RN3.1 (common), U1.2 (A0), U1.3 (A1), U1.4 (A2), U1.5 (A3), U1.6 (A4), U1.7 (A5), U1.8 (A6), U1.9 (A7), U1.10 (GND), U2.29 (GND), U3.1 (A14), U3.14 (GND), U4.10 (GND), U5.14 (GND), U5.27 (A14), U6.4 (E), U6.5 (D), U6.7 (GND), U6.9 (D), U6.10 (E), U7.2 (Mr), U7.7 (GND), U8.7 (VSS), U9.8 (GND), U10.7 (GND), U11.7 (GND), U11.9, U11.10, U11.12, U11.13, U12.7 (GND), U12.9, U12.10, U13.7 (GND), U14.7 (GND), U15.7 (GND), U16.7 (GND), U18.2 (D), U18.3 (Cp), U18.4 (Sd), U18.7 (GND), U19.7 (GND), U21.7 (GND), U22.2 (A0), U22.10 (GND), U23.1, U23.7 (GND), U24.7 (GND), U27.8 (GND), U28.7 (GND), U29.7 (GND)
unnamed: C1.1, R29.2, U21.1, Y1.1
unnamed: C2.1, R30.1, Y1.2
unnamed: C3.1, R59.1
unnamed: C3.2, C7.1, CO3.2, R58.2
unnamed: C6.1, R56.1
unnamed: C6.2, C8.1, CO2.2, R57.2
unnamed: CO4.8, R23.1
unnamed: D2.2 (A), J2.2
unnamed: D4.2 (A), J2.4
unnamed: D5.2 (A), J2.5
unnamed: D6.2 (A), J2.6
unnamed: D7.2 (A), J2.7
unnamed: D8.2 (A), J2.8
unnamed: D13.2 (A), Q8.2 (B), R48.1, R49.1
unnamed: J1.1, R21.1
unnamed: JP4.1, RP1.7 (R6), U22.3 (A1)
unnamed: Q8.1 (E), R50.2
unnamed: Q9.1 (E), R80.2
unnamed: Q9.2 (B), R59.2, R70.1, R79.2
unnamed: R10.2, RP2.9 (R8), U1.11 (Y7), U2.15 (D1)
unnamed: R11.2, RP2.8 (R7), U1.12 (Y6), U2.14 (D0)
unnamed: R12.2, RP2.7 (R6), U1.13 (Y5), U2.13 (D7)
unnamed: R13.2, RP2.6 (R5), U1.14 (Y4), U2.12 (D2)
unnamed: R14.2, RP2.5 (R4), U1.15 (Y3), U2.10 (D6)
unnamed: R15.2, RP2.4 (R3), U1.16 (Y2), U2.9 (D5)
unnamed: R16.2, RP2.3 (R2), U1.17 (Y1), U2.8 (D3)
unnamed: R17.2, RP2.2 (R1), U1.18 (Y0), U2.7 (D4)
unnamed: R20.2, U12.6
unnamed: R29.1, R30.2, U7.1 (Cp), U21.2
unnamed: R42.2, U23.11
unnamed: R43.2, U23.8
unnamed: R48.2, U11.3
unnamed: U8.1, U10.2 (IN2)
unnamed: U10.4 (IN1), U18.9 (Q)
unnamed: U10.6 (OUT), U11.1
unnamed: U10.8 (OUT), U18.12 (D)
unnamed: U12.1, U21.10
unnamed: U12.2, U15.8
unnamed: U12.5, U21.8
unnamed: U4.1 (OE), U6.1 (E), U12.11
unnamed: U13.1, U19.11
unnamed: U13.9, U16.8
unnamed: U13.10, U13.11, U19.4
unnamed: U13.8, U13.12, U19.13
unnamed: U13.13, U19.3
unnamed: U14.3 (Q0), U15.1
unnamed: U14.4 (Q1), U15.2
unnamed: U14.5 (Q2), U15.13
unnamed: U8.5, U8.12, U14.8 (Q3), U15.5
unnamed: U8.4, U8.11, U14.9 (Q2), U15.4
unnamed: U8.10, U14.10 (Q1), U21.5
unnamed: U8.2, U14.11 (Q0), U21.3
unnamed: U14.6 (Q3), U14.13 (Cp), U15.10
unnamed: U15.6, U15.11
unnamed: U15.9, U15.12
unnamed: U16.3, U16.4
unnamed: U19.8, U21.11
unnamed: U8.9, U21.4
unnamed: U8.3, U21.6
unnamed: U21.12, U23.9
unnamed: U21.13, U23.6, U23.12
unnamed: U23.3, U23.5
unnamed: U23.4, U24.3
unnamed: U23.10, U23.13, U24.6
unnamed: U24.9, U27.9 (O6)
unnamed: U24.10, U27.7 (O7), U28.2 (D)
unnamed: U24.11, U29.3 (Cp), U29.11 (Cp)
unnamed: U28.5 (Q), U29.2 (D)
unnamed: U28.8 (~Q), U29.12 (D), U29.13 (Cd)

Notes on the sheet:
Expansion port
Inverting the CPU clock improves ROM timing
32K (16/8K used) OTP/EEPROM 27C256
Change over jumpers for
Also switch over JP10
to generate "loading bars"
Address Bus
Address Bus
Used as inverter
16K
count column of displayed characters
pixel data
NMI logic
To invert screen Scratch default connection of JP5an JP6 and swap connections
KEY
Cut trace to disconnect pin 1
Select ROM for first 8K or 16K
. . . . .
Cassette input
Data Bus
Bus can override selects
22K x 8
or 32K (8K used) EEEPROM 28C256
Select one of 64 possible
NOP generator
10K x 6
32K
CPU NOP enforcer
with patch wire
Video Bus
GND/A13
for printer detection
CPU Control Bus
CPU (Z80 4MHz)
place jumper for NTSC (60Hz)
Pullups for IORD
For 28C256
two blocks of 8K used when set for 16K
5V (USB power) input
on floating bus

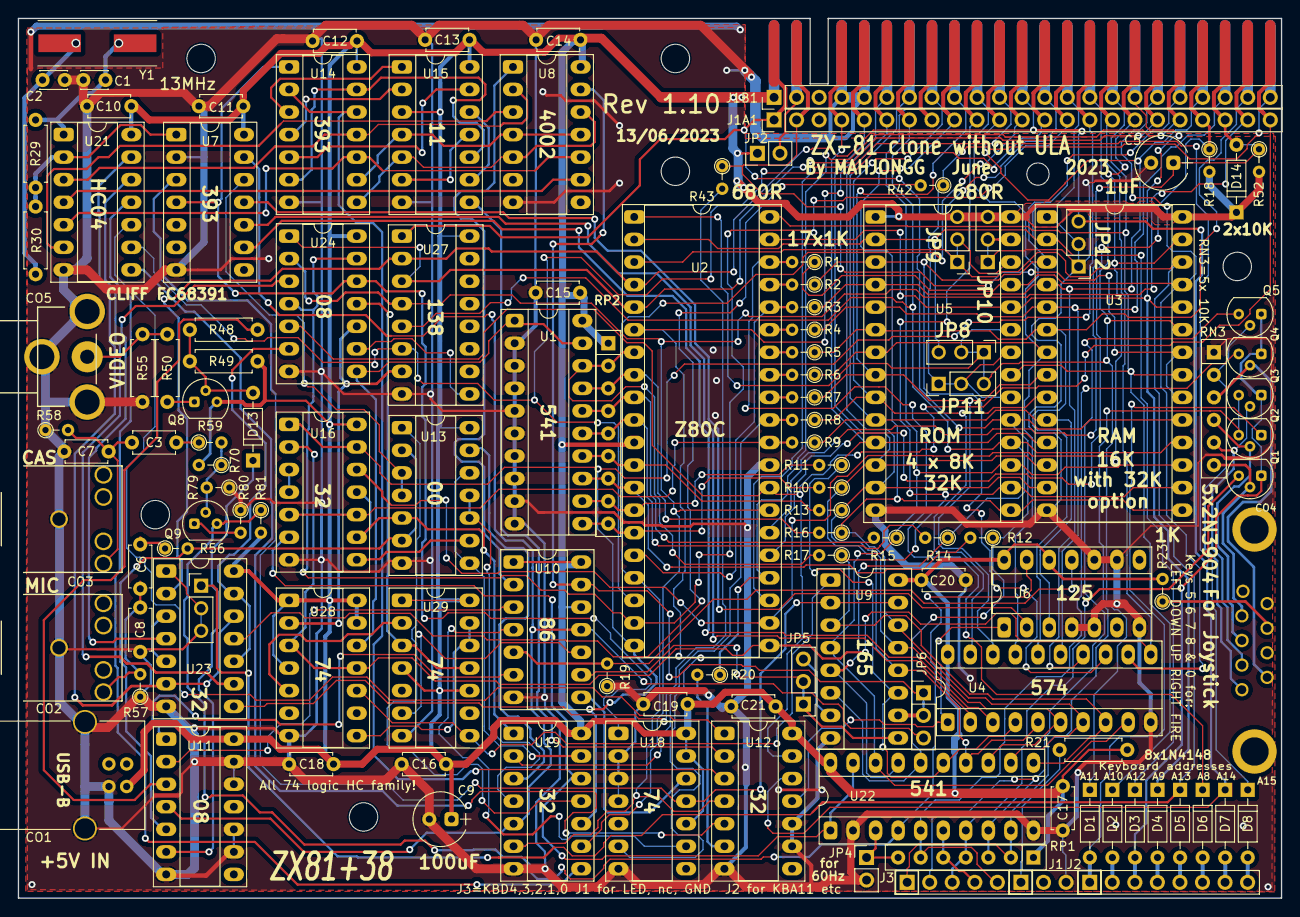
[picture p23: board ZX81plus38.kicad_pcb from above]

Board: 2 copper layers, 142.2 x 99.1 mm, 132 parts (0 on the bottom side), 154 nets.

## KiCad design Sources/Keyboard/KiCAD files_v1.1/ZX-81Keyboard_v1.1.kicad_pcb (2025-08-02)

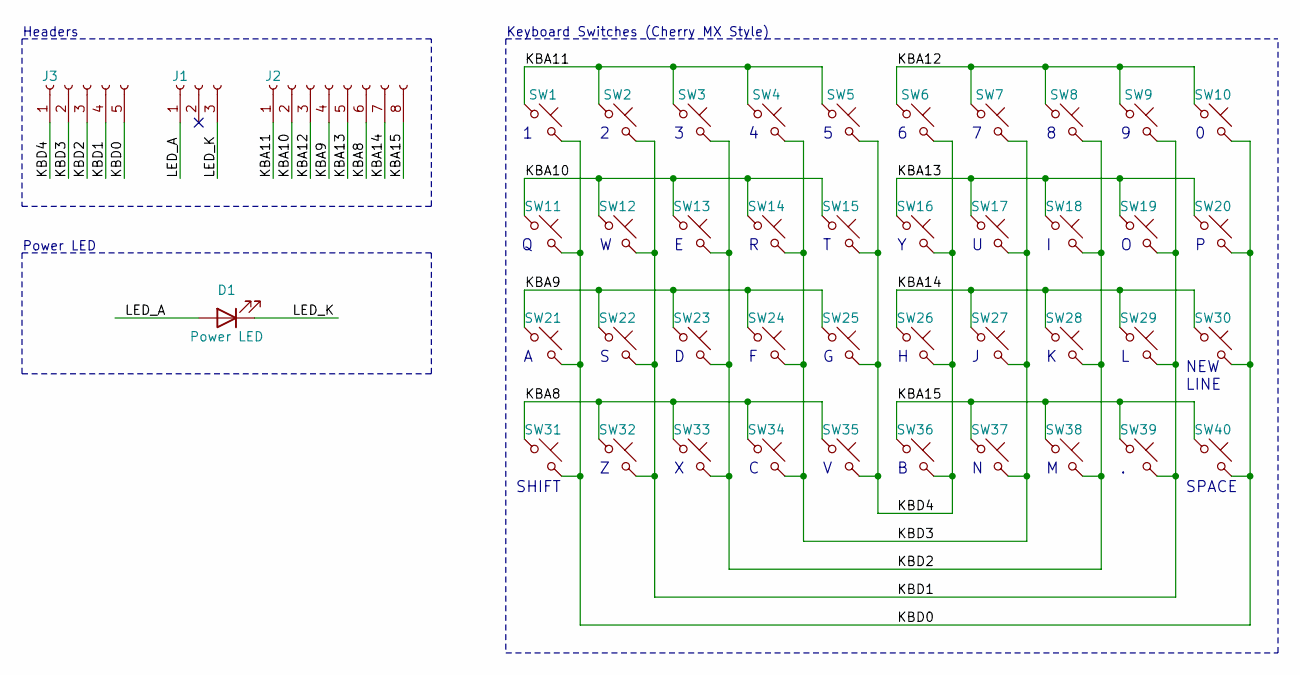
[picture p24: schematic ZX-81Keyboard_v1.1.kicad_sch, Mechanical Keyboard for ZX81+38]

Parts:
D1: Power LED; LED_1206_3216Metric_Pad1.42x1.75mm_HandSolder
J1: Conn_01x03_Female; PinSocket_1x03_P2.54mm_Vertical
J2: Conn_01x08_Female; PinSocket_1x08_P2.54mm_Vertical
J3: Conn_01x05_Female; PinSocket_1x05_P2.54mm_Vertical
SW1: 1; SW_Cherry_MX_1.00u_PCB
SW2: 2; SW_Cherry_MX_1.00u_PCB
SW3: 3; SW_Cherry_MX_1.00u_PCB
SW4: 4; SW_Cherry_MX_1.00u_PCB
SW5: 5; SW_Cherry_MX_1.00u_PCB
SW6: 6; SW_Cherry_MX_1.00u_PCB
SW7: 7; SW_Cherry_MX_1.00u_PCB
SW8: 8; SW_Cherry_MX_1.00u_PCB
SW9: 9; SW_Cherry_MX_1.00u_PCB
SW10: 0; SW_Cherry_MX_1.00u_PCB
SW11: Q; SW_Cherry_MX_1.00u_PCB
SW12: W; SW_Cherry_MX_1.00u_PCB
SW13: E; SW_Cherry_MX_1.00u_PCB
SW14: R; SW_Cherry_MX_1.00u_PCB
SW15: T; SW_Cherry_MX_1.00u_PCB
SW16: Y; SW_Cherry_MX_1.00u_PCB
SW17: U; SW_Cherry_MX_1.00u_PCB
SW18: I; SW_Cherry_MX_1.00u_PCB
SW19: O; SW_Cherry_MX_1.00u_PCB
SW20: P; SW_Cherry_MX_1.00u_PCB
SW21: A; SW_Cherry_MX_1.00u_PCB
SW22: S; SW_Cherry_MX_1.00u_PCB
SW23: D; SW_Cherry_MX_1.00u_PCB
SW24: F; SW_Cherry_MX_1.00u_PCB
SW25: G; SW_Cherry_MX_1.00u_PCB
SW26: H; SW_Cherry_MX_1.00u_PCB
SW27: J; SW_Cherry_MX_1.00u_PCB
SW28: K; SW_Cherry_MX_1.00u_PCB
SW29: L; SW_Cherry_MX_1.00u_PCB
SW30: NEW LINE; SW_Cherry_MX_1.00u_PCB
SW31: SHIFT; SW_Cherry_MX_1.00u_PCB
SW32: Z; SW_Cherry_MX_1.00u_PCB
SW33: X; SW_Cherry_MX_1.00u_PCB
SW34: C; SW_Cherry_MX_1.00u_PCB
SW35: V; SW_Cherry_MX_1.00u_PCB
SW36: B; SW_Cherry_MX_1.00u_PCB
SW37: N; SW_Cherry_MX_1.00u_PCB
SW38: M; SW_Cherry_MX_1.00u_PCB
SW39: .; SW_Cherry_MX_1.00u_PCB
SW40: SPACE; SW_Cherry_MX_1.00u_PCB

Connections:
/KBA8: J2.6, SW31.1, SW32.1, SW33.1, SW34.1, SW35.1
/KBA9: J2.4, SW21.1, SW22.1, SW23.1, SW24.1, SW25.1
/KBA10: J2.2, SW11.1, SW12.1, SW13.1, SW14.1, SW15.1
/KBA11: J2.1, SW1.1, SW2.1, SW3.1, SW4.1, SW5.1
/KBA12: J2.3, SW6.1, SW7.1, SW8.1, SW9.1, SW10.1
/KBA13: J2.5, SW16.1, SW17.1, SW18.1, SW19.1, SW20.1
/KBA14: J2.7, SW26.1, SW27.1, SW28.1, SW29.1, SW30.1
/KBA15: J2.8, SW36.1, SW37.1, SW38.1, SW39.1, SW40.1
/KBD0: J3.5, SW1.2, SW10.2, SW11.2, SW20.2, SW21.2, SW30.2, SW31.2, SW40.2
/KBD1: J3.4, SW2.2, SW9.2, SW12.2, SW19.2, SW22.2, SW29.2, SW32.2, SW39.2
/KBD2: J3.3, SW3.2, SW8.2, SW13.2, SW18.2, SW23.2, SW28.2, SW33.2, SW38.2
/KBD3: J3.2, SW4.2, SW7.2, SW14.2, SW17.2, SW24.2, SW27.2, SW34.2, SW37.2
/KBD4: J3.1, SW5.2, SW6.2, SW15.2, SW16.2, SW25.2, SW26.2, SW35.2, SW36.2
/LED_A: D1.2 (A), J1.1
/LED_K: D1.1 (K), J1.3

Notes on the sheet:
SPACE
Headers
SHIFT
Power LED
NEW LINE
Keyboard Switches (Cherry MX Style)

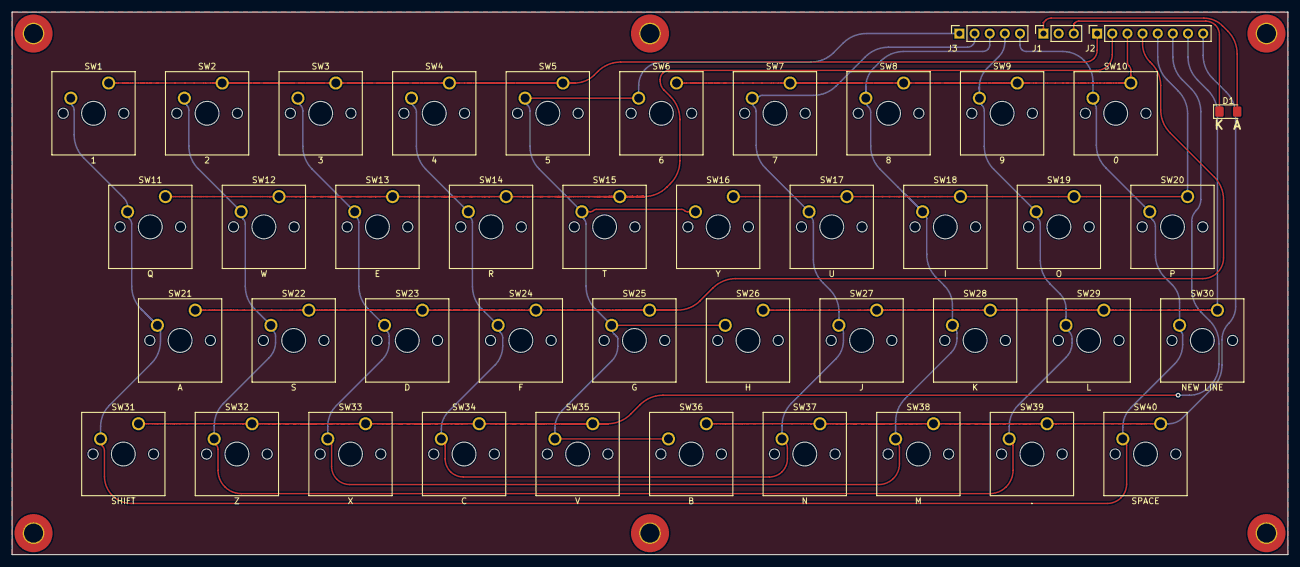
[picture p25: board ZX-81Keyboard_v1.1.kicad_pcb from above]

Board: 2 copper layers, 214.0 x 91.0 mm, 44 parts (0 on the bottom side), 15 nets.

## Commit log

2025-08-02 added 3D case models
    [combined-zx81-case-timex.step, combined-zx81-case-zx81.step, zx81-case-bottom-timex.step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]
2025-08-10 Add files via upload
    Nearly there.
    Ordered some caps to make it right.
    I have some but the footprint isn’t correct and want it to be right.
2025-08-17 Create Assembly
